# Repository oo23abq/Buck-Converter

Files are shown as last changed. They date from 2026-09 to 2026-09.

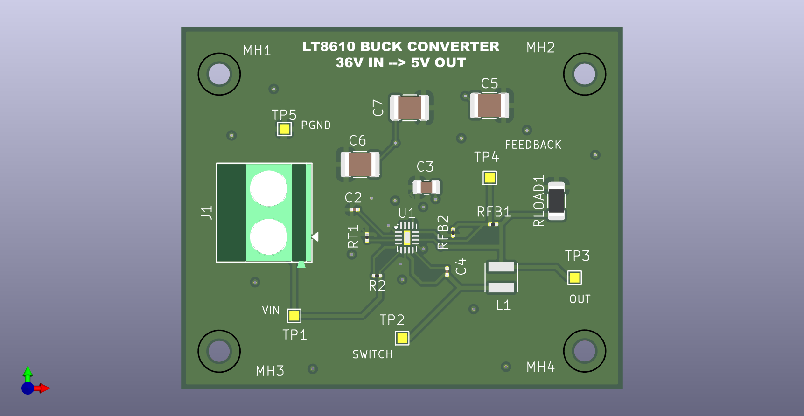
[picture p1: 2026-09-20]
kicad/images/buckconvertertop.png

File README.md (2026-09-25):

# Basic-Buck-Converter-PCB

This repository contains the full design, simulation, documentation, and PCB layout for a compact buck (step‑down) DC‑DC converter. It is intended as a small, practical companion board to a more advanced isolated flyback converter, providing a simple, efficient, and well‑documented reference design for low‑voltage power conversion.

The project includes LTspice simulations, KiCad schematic + PCB, design calculations, and live testing and wiring. 
🔧 Project Overview

The board will take a DC input and step it down to low‑voltage output using a synchronous switching topology. 

Design Focuses: 

* Compact PCB footprint
* Good efficiency across a wide input range
* Clean documentation and reproducible calculations
* Practical testability (scope points, connectors, PG indicator)

Recruiter‑friendly presentation on GitHub

🎯 Target Electrical Specifications
* Parameter	Target
* Input Voltage	7–24 V DC
* Output Voltage	5 V (adjustable via feedback divider)
* Output Current	1–2 A depending on regulator choice
* Switching Frequency	500 kHz – 2 MHz (IC‑dependent)
* Duty Cycle ≈ 0.42
* Output Ripple	≤ 50 mVpp
* Inductor Ripple	20–40% of Iout

These values will be refined once the LTspice schematic is finalised.

📐 LTspice Simulations Included

The following was simulated fully in LTspice: 

* Output voltage regulation
* Output ripple measurement
* Inductor current ripple
* Switch node waveform
* Startup behaviour
* Load step response
* Line step response
* Efficiency vs load sweep

## Repository Structure

```text
├── docs/                               # General Documentation 
│   └── testreport.docx                 # Lab Test Report
├── kicad/                              # KiCAD Project Files 
│   ├── Buck Converter.kicad_pcb        # PCB Board File 
│   ├── Buck Converter.kicad_sch        # Schematic File 
│   ├── bom.csv                         # Bill of Materials
│   ├── gerber/                         # Manufacturing Files 
│   │   └── buck.zip                    # Gerber, NC Drill Files 
│   └── images/                         # 3D PCB Renders 
│       ├── buckconverterbottom.png     # Bottom Layer
│       └── buckconvertertop.png        # Top Layer 
├── ltspice/                            # Analog Simulation Files 
│   ├── models.asc                      # Component Models 
│   └── schematic.asc                   # LTspice schematic
├── testing/                            # Lab Testing
│   ├── oscilloscopeinput.png           # Input Ripple Waveforms 
│   ├── oscilloscopeoutput.png          # Output transient response waveform
│   └── testsetup.png                   # Bench Test Setup 
├── LICENSE                             # MIT Licence File 
└── README.md                           # Guidance / info

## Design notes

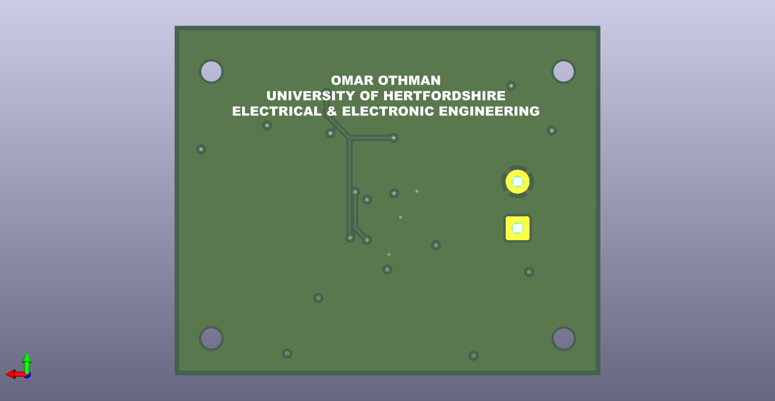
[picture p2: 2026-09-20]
kicad/images/buckconverterbottom.png

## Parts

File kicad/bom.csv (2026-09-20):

Reference | Qty | Value | DNP | Exclude from BOM | Exclude from Board | Footprint | Datasheet
C2 | 1 | 10n |  |  |  | Capacitor_SMD:C_0201_0603Metric
C3 | 1 | 4.7µ |  |  |  | Capacitor_SMD:C_0805_2012Metric
C4 | 1 | 0.1µ |  |  |  | Capacitor_SMD:C_0201_0603Metric
C5,C6 | 2 | 22µ |  |  |  | Capacitor_SMD:C_1210_3225Metric
C7 | 1 | 47µ |  |  |  | Capacitor_SMD:C_1210_3225Metric
J1 | 1 | Conn_01x02_Pin |  |  |  | TerminalBlock_Phoenix:TerminalBlock_Phoenix_MKDS-1,5-2-5.08_1x02_P5.08mm_Horizontal | ~
L1 | 1 | 10µ |  |  |  | Inductor_SMD:L_Neosid_SMS-ME3015
R2,RFB2,RT1 | 3 | 100k |  |  |  | Resistor_SMD:R_0201_0603Metric
RFB1 | 1 | 425k |  |  |  | Resistor_SMD:R_0201_0603Metric
RLOAD1 | 1 | 2.5 |  |  |  | Resistor_SMD:R_1206_3216Metric
TP1,TP2,TP3,TP4,TP5 | 5 | TestPoint |  |  |  | TestPoint:TestPoint_Pad_1.0x1.0mm | ~
U1 | 1 | LT8610 |  |  |  | Package_DFN_QFN:QFN-16-1EP_1.8x2.6mm_P0.4mm_EP0.7x1.5mm

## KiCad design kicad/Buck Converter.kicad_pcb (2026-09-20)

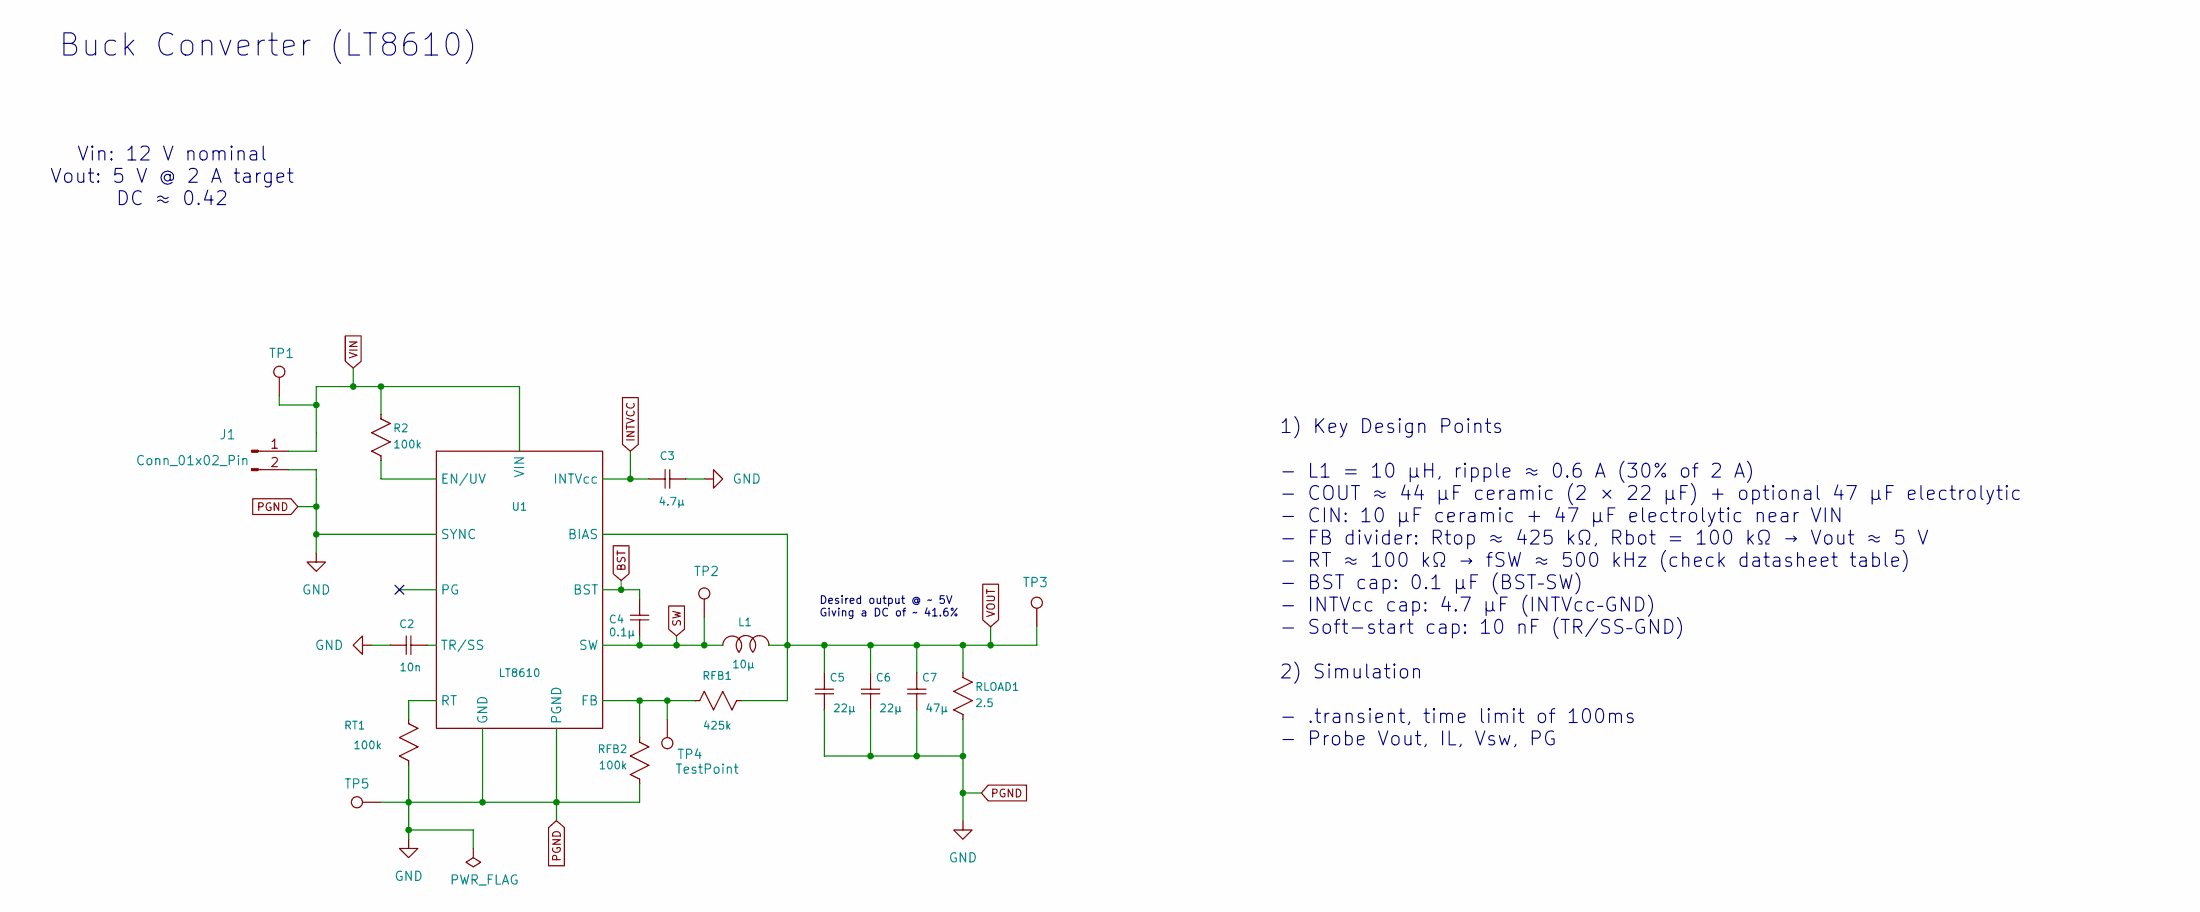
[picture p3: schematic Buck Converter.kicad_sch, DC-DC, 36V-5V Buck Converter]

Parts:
C2: 10n; C_0201_0603Metric
C3: 4.7µ; C_0805_2012Metric
C4: 0.1µ; C_0201_0603Metric
C5, C6: 22µ; C_1210_3225Metric
C7: 47µ; C_1210_3225Metric
J1: Conn_01x02_Pin; TerminalBlock_Phoenix_MKDS-1,5-2-5.08_1x02_P5.08mm_Horizont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
L1: 10µ; L_Neosid_SMS-ME3015
R2: 100k; R_0201_0603Metric
RFB1: 425k; R_0201_0603Metric
RFB2: 100k; R_0201_0603Metric
RLOAD1: 2.5; R_1206_3216Metric
RT1: 100k; R_0201_0603Metric
TP1, TP2, TP3, TP4, TP5: TestPoint; TestPoint_Pad_1.0x1.0mm
U1: LT8610; QFN-16-1EP_1.8x2.6mm_P0.4mm_EP0.7x1.5mm

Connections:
BST: C4.1, U1.8 (BST)
INTVCC: C3.1, U1.9 (INTVcc)
unnamed: R2.2, U1.4 (EN/UV)
unnamed: RFB1.1, RFB2.2, TP4.1, U1.12 (FB)
unnamed: RT1.1, U1.3 (RT)
unnamed: C2.1, U1.2 (TR/SS)
PGND: C2.2, C3.2, C5.2, C6.2, C7.2, J1.2, RFB2.1, RLOAD1.2, RT1.2, TP5.1, U1.1 (SYNC), U1.6 (PGND), U1.13 (GND)
SW: C4.2, L1.1, TP2.1, U1.7 (SW)
VIN: J1.1, R2.1, TP1.1, U1.5 (VIN)
VOUT: C5.1, C6.1, C7.1, L1.2, RFB1.2, RLOAD1.1, TP3.1, U1.10 (BIAS)

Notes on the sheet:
Desired output @ ~ 5V Giving a DC of ~ 41.6%
Buck Converter (LT8610)
Vin: 12 V nominal Vout: 5 V @ 2 A target DC ≈ 0.42
1) Key Design Points - L1 = 10 µH, ripple ≈ 0.6 A (30% of 2 A) - COUT ≈ 44 µF ceramic (2 × 22 µF) + optional 47 µF electrolytic - CIN: 10 µF ceramic + 47 µF electrolytic near VIN - FB divider: Rtop ≈ 425 kΩ, Rbot = 100 kΩ → Vout ≈ 5 V - RT ≈ 100 kΩ → fSW ≈ 500 kHz (check datasheet table) - BST cap: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

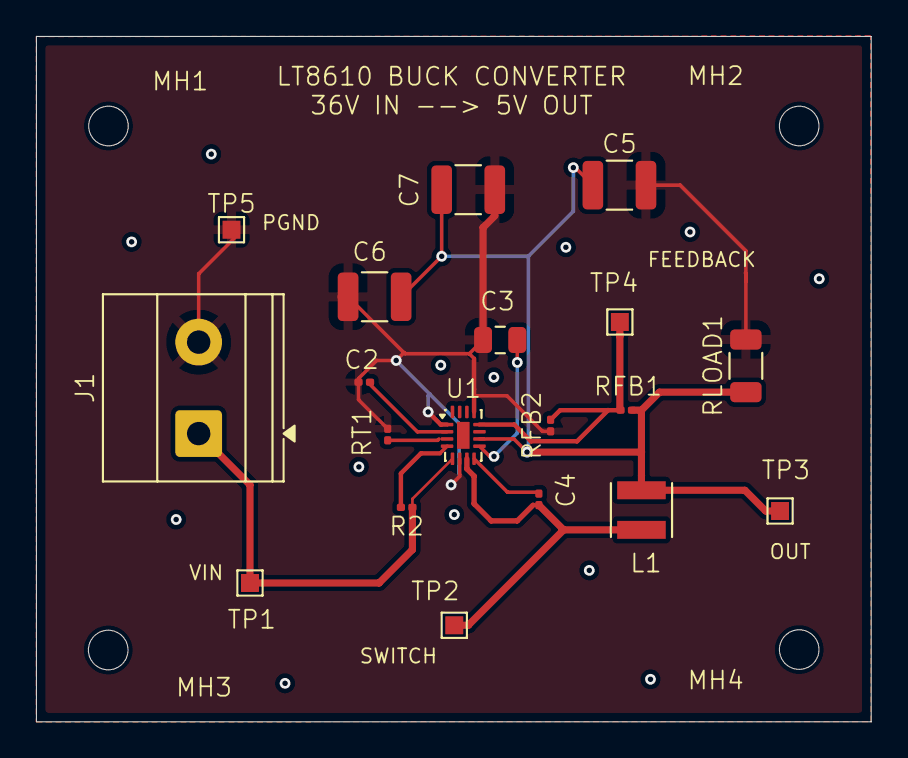
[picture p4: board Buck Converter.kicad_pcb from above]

Board: 2 copper layers, 46.4 x 38.1 mm, 23 parts (0 on the bottom side), 10 nets.

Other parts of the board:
MH1, MH2, MH3, MH4: MountingHole_2.2mm_M2
